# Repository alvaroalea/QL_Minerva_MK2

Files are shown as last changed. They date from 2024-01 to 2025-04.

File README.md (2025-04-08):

# SINCLAIR QL - Minerva MK II - New OS + RTC

In 2024 by Alvaro Alea Fernandez

License under: CERN Open Hardware Licence Version 2 - Strongly Reciprocal

https://ohwr.org/cern_ohl_s_v2.txt

My work is only copy the design to Kicad, all (C) are retaing to the original owners.

U1 shall be pin row, to be mounted in the solder side, in a way that allow to insert on the Sinclair QL's Rom socket.

U5 shall be solder without socket under U2.

U2 shall be solder with a socket to allow space for U5.

Original Information of minerva can be found here: http://tfs.firshman.co.uk/ql/minerva.htm

A generic description here: https://wiki.qlforum.co.uk/doku.php?id=qlwiki:minerva

Manuals and software here: https://dilwyn.qlforum.co.uk/docs/manuals/index.html

Main information, GAL code, pictures, etc... has been obtained from this post: https://qlforum.co.uk/viewtopic.php?t=1993

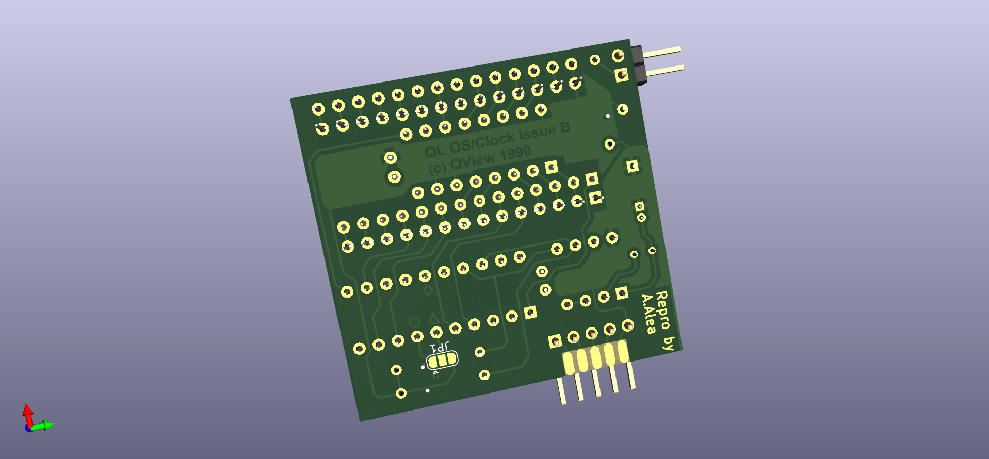
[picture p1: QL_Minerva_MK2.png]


ROM Chip shall be installed as per this picture:

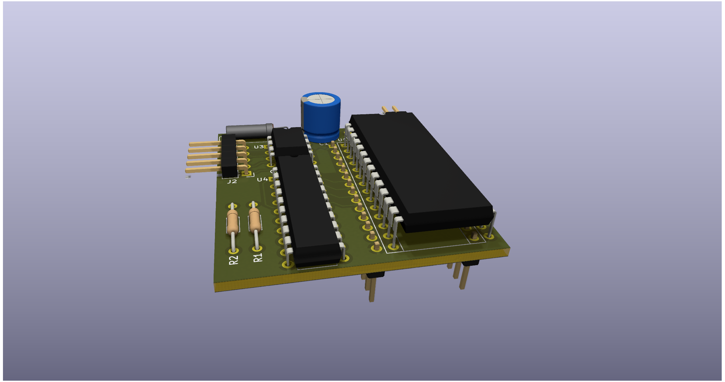
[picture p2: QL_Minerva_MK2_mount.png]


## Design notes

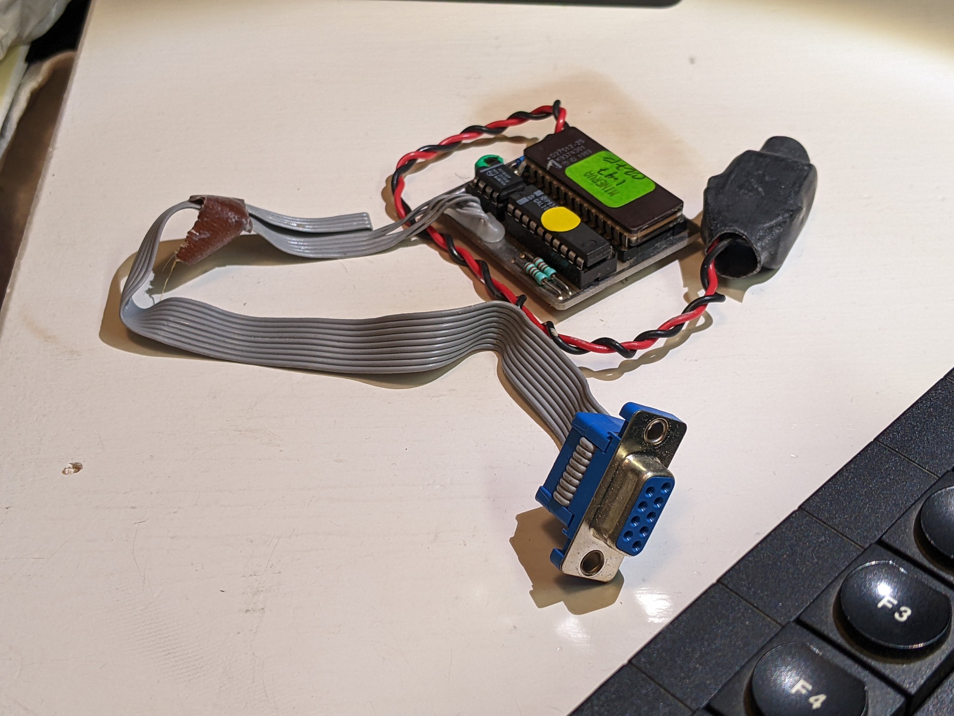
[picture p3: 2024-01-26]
docs_and_pics/417425589_10160796980898964_1513806570932412585_n.jpg

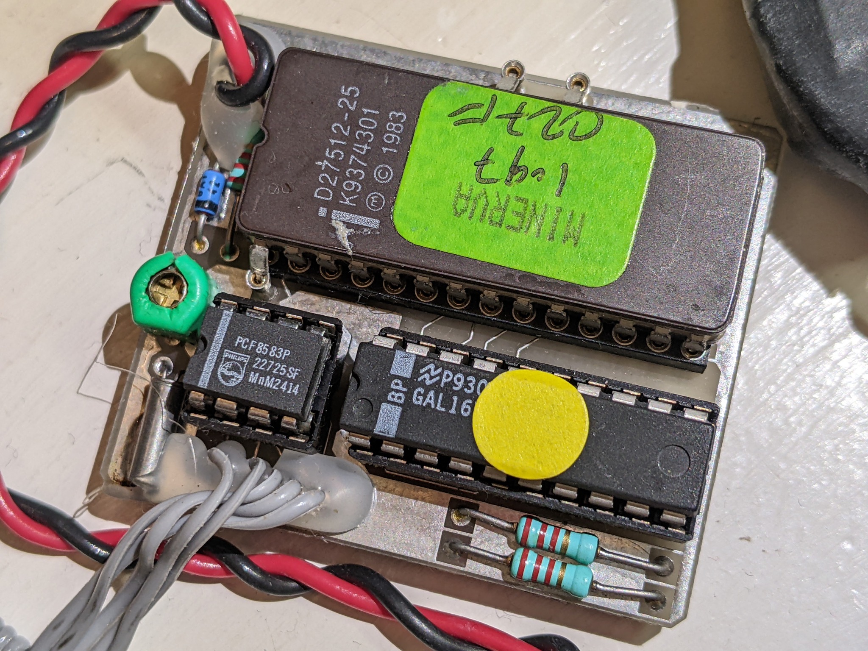
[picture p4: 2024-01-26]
docs_and_pics/417457922_10160796980883964_8911913954346071387_n.jpg

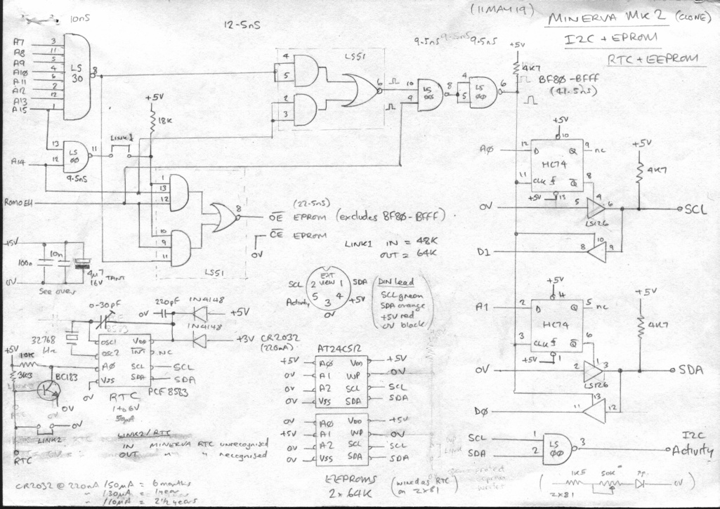
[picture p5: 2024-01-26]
docs_and_pics/MK2clone.JPG

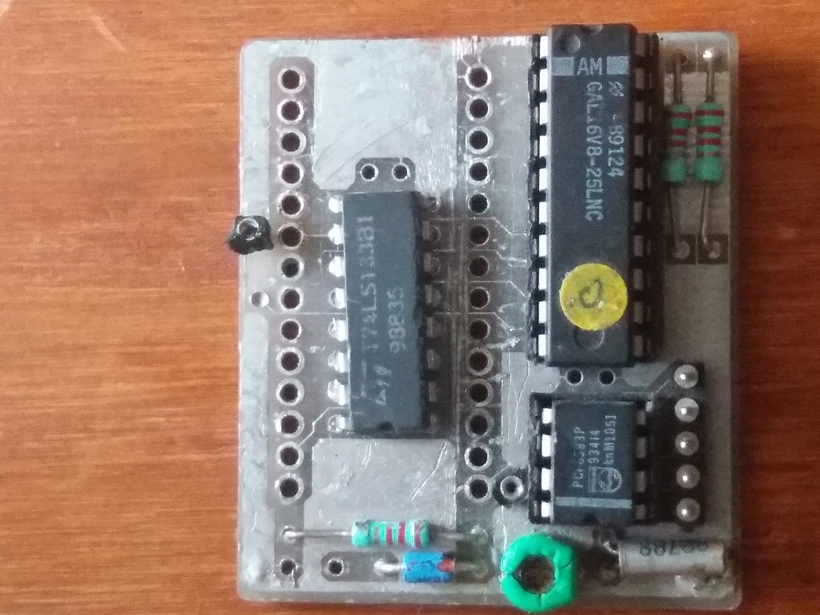
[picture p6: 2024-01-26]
docs_and_pics/MinervaMKII-1.jpg

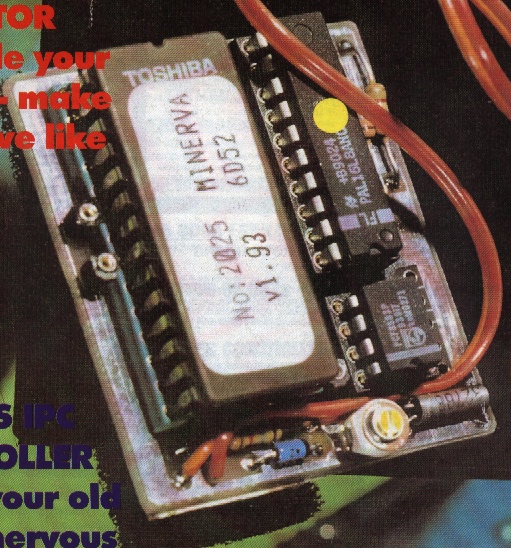
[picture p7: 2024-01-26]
docs_and_pics/Mk2photo.JPG

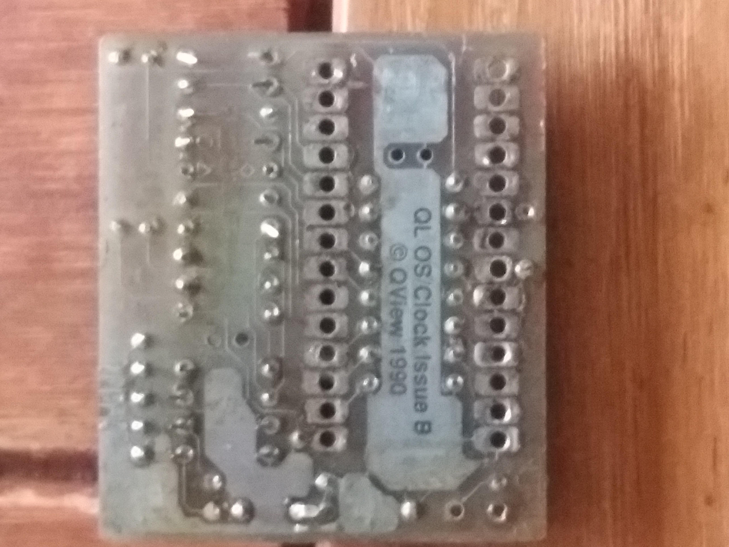
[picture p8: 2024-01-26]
docs_and_pics/MinervaMKII-3.jpg

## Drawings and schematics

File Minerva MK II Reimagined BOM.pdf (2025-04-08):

# Minerva MK II Reimagi… Rev: 0.0

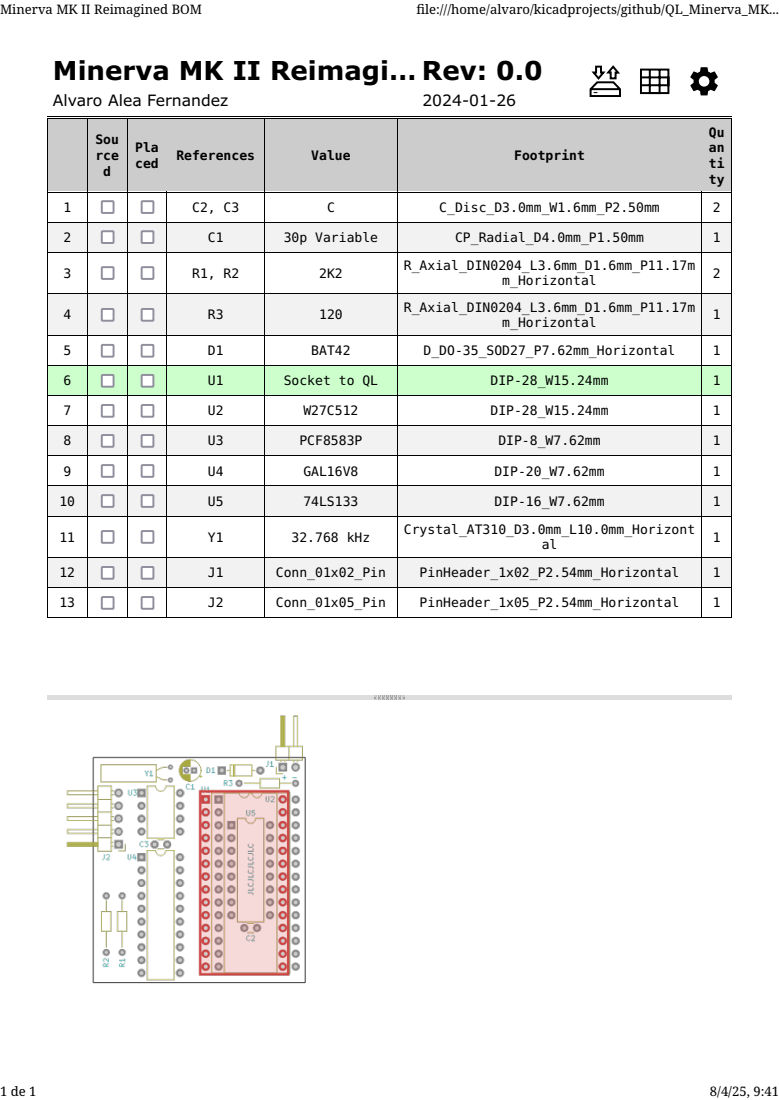
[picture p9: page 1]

Sou rce d | Pla ced | References | Value | Footprint | Qu an ti ty

1 | | | C2, C3 | C | C_Disc_D3.0mm_W1.6mm_P2.50mm | 2

2 | | | C1 | 30p Variable | CP_Radial_D4.0mm_P1.50mm | 1

3 | | | R1, R2 | 2K2 | R_Axial_DIN0204_L3.6mm_D1.6mm_P11.17m m_Horizontal | 2

4 | | | R3 | 120 | R_Axial_DIN0204_L3.6mm_D1.6mm_P11.17m m_Horizontal | 1

5 | | | D1 | BAT42 | D_DO-35_SOD27_P7.62mm_Horizontal | 1

6 | | | U1 | Socket to QL | DIP-28_W15.24mm | 1

7 | | | U2 | W27C512 | DIP-28_W15.24mm | 1

8 | | | U3 | PCF8583P | DIP-8_W7.62mm | 1

9 | | | U4 | GAL16V8 | DIP-20_W7.62mm | 1

10 | | | U5 | 74LS133 | DIP-16_W7.62mm | 1

11 | | | Y1 | 32.768 kHz | Crystal_AT310_D3.0mm_L10.0mm_Horizont al | 1

12 | | | J1 | Conn_01x02_Pin | PinHeader_1x02_P2.54mm_Horizontal | 1

13 | | | J2 | Conn_01x05_Pin | PinHeader_1x05_P2.54mm_Horizontal | 1

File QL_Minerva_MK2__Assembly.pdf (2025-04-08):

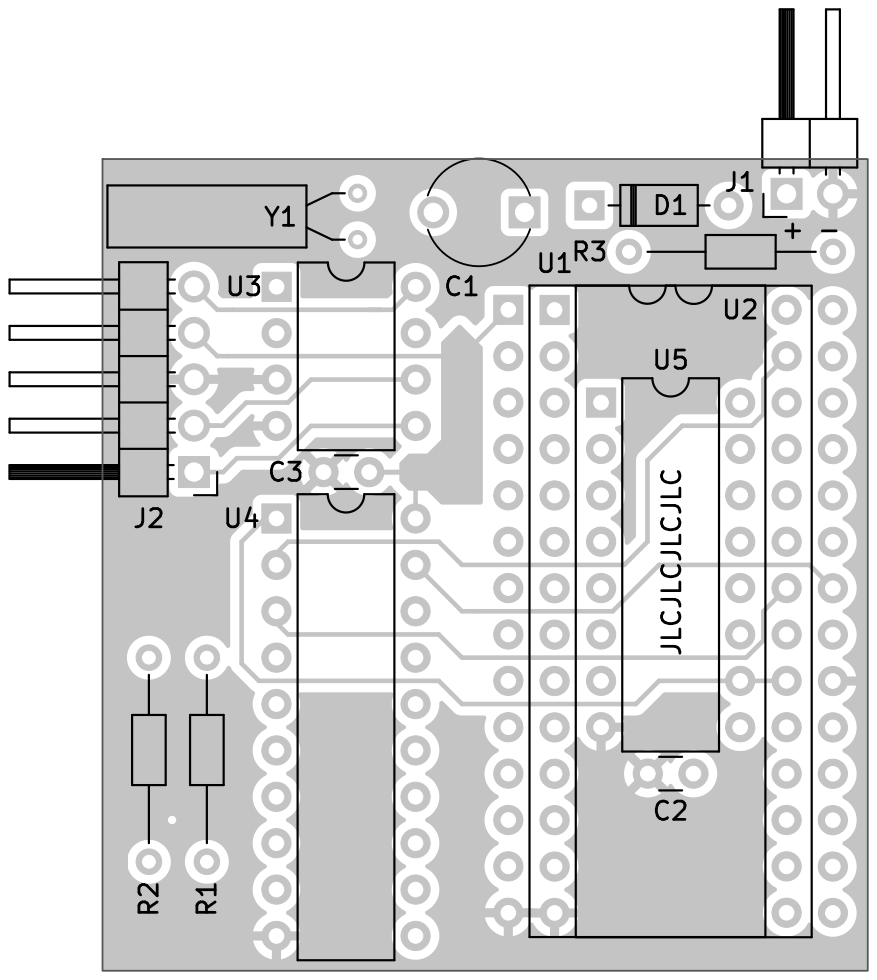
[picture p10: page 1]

Id: /1 Title: Minerva MK II Reimagined

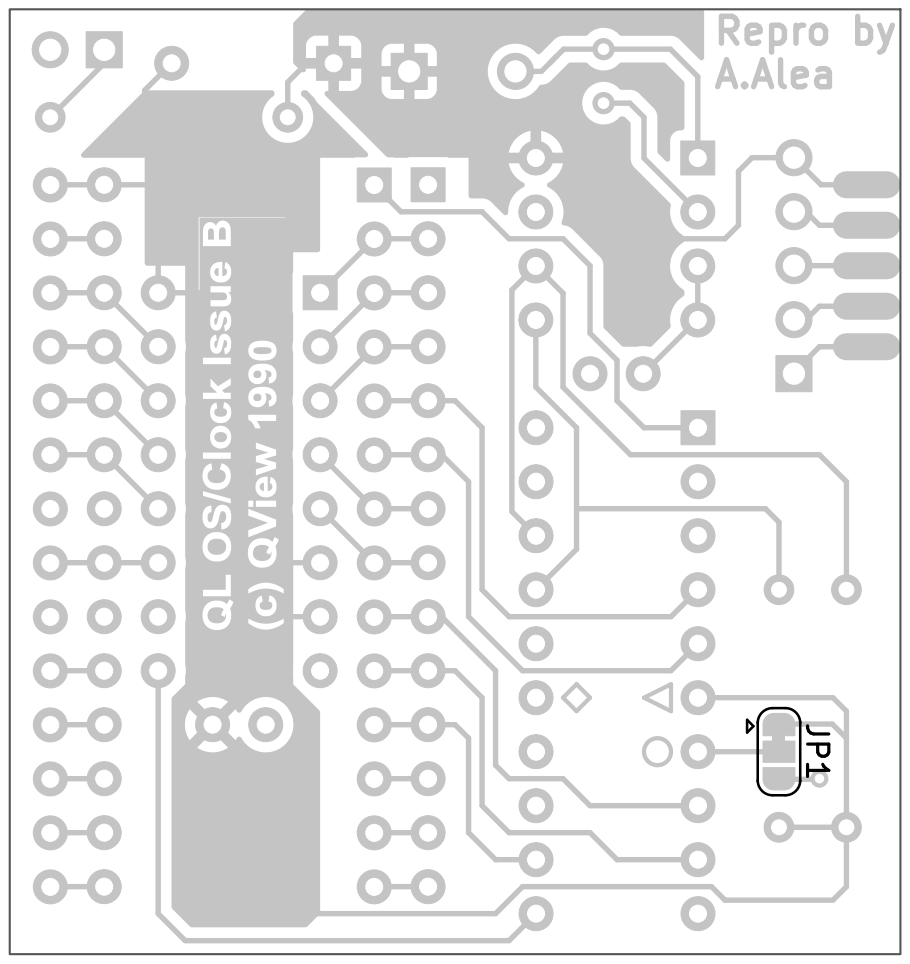
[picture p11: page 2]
Repro by A.AleaJP1; D Date: 2024-01-26 KiCad; E.D.A. 9.0.0 Size: A4; Rev: 0.0; File: QL_Minerva_MK2.kicad_pcb Sheet: Black; And; White; BOT Alvaro Alea; Fernandez Board2Pdf:; Black; BOT -; Page 2/4

Id: /1 Title: Minerva MK II Reimagined

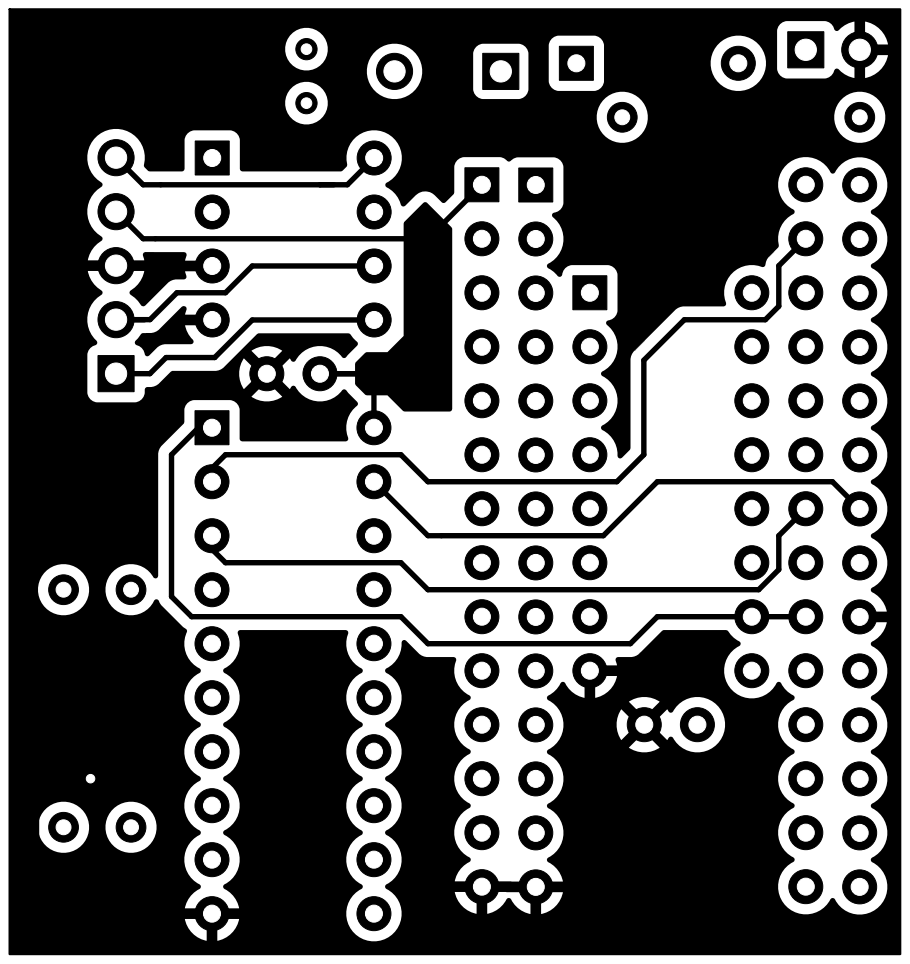
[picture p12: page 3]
D Date: 2024-01-26 KiCad; E.D.A. 9.0.0 Size: A4; Rev: 0.0; File: QL_Minerva_MK2.kicad_pcb Sheet: Black; And; White; TOP-Tracks Alvaro Alea; Fernandez Board2Pdf:; Black; TOP-Tracks; Page 3/4

Id: /1 Title: Minerva MK II Reimagined

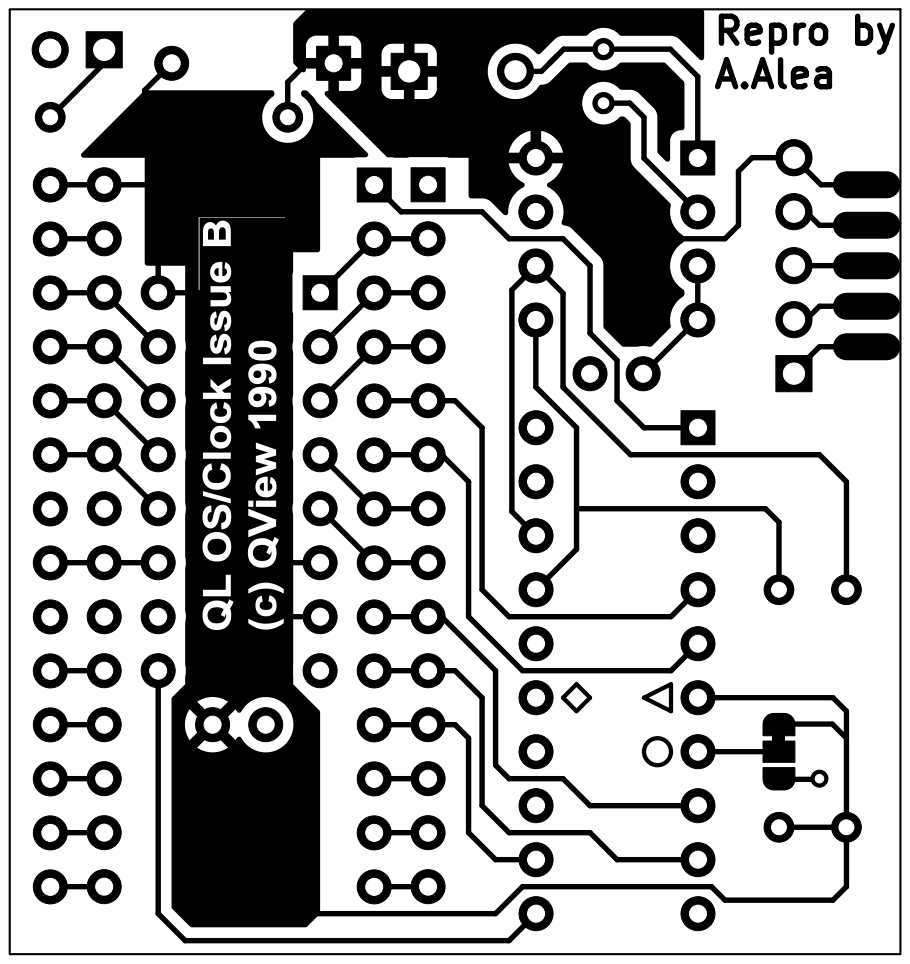
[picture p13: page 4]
Repro by A.Alea 1; D Date: 2024-01-26 KiCad; E.D.A. 9.0.0 Size: A4; Rev: 0.0; File: QL_Minerva_MK2.kicad_pcb Sheet: Black; And; White; BOT-Tracks Alvaro Alea; Fernandez Board2Pdf:; Black; BOT-Tracks; Page 4/4

Id: /1 Title: Minerva MK II Reimagined

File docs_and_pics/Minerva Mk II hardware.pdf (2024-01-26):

## PCB layout and schematic

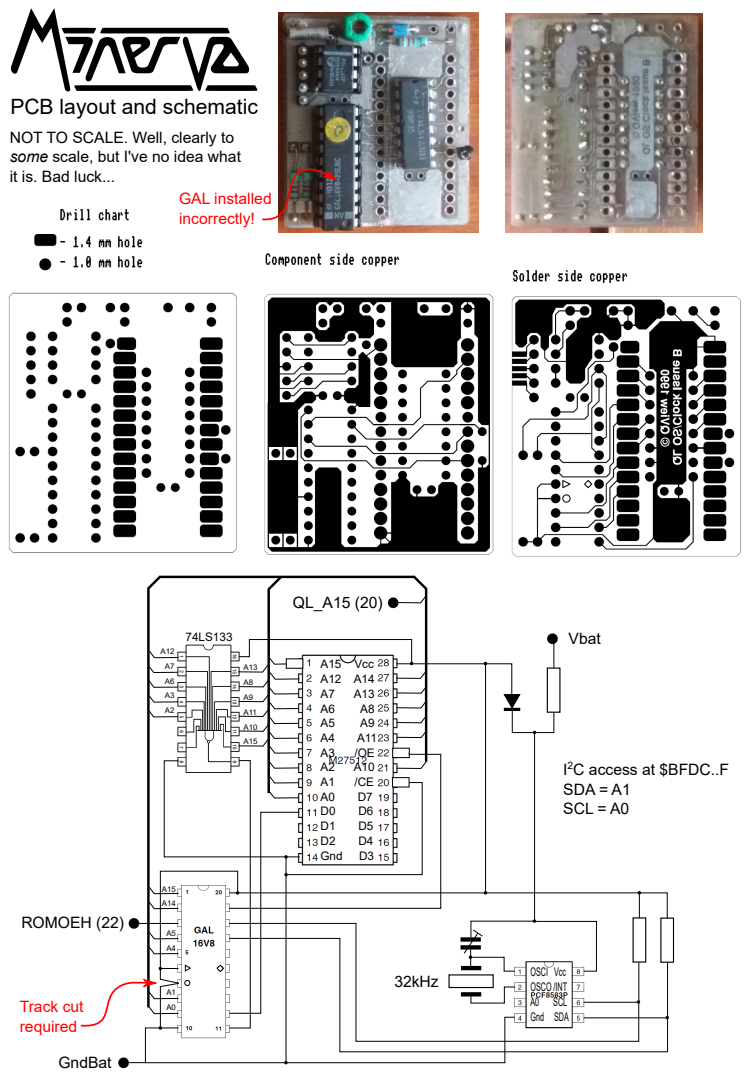
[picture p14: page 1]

NOT TO SCALE. Well, clearly to
some scale, but I've no idea what
it is. Bad luck...

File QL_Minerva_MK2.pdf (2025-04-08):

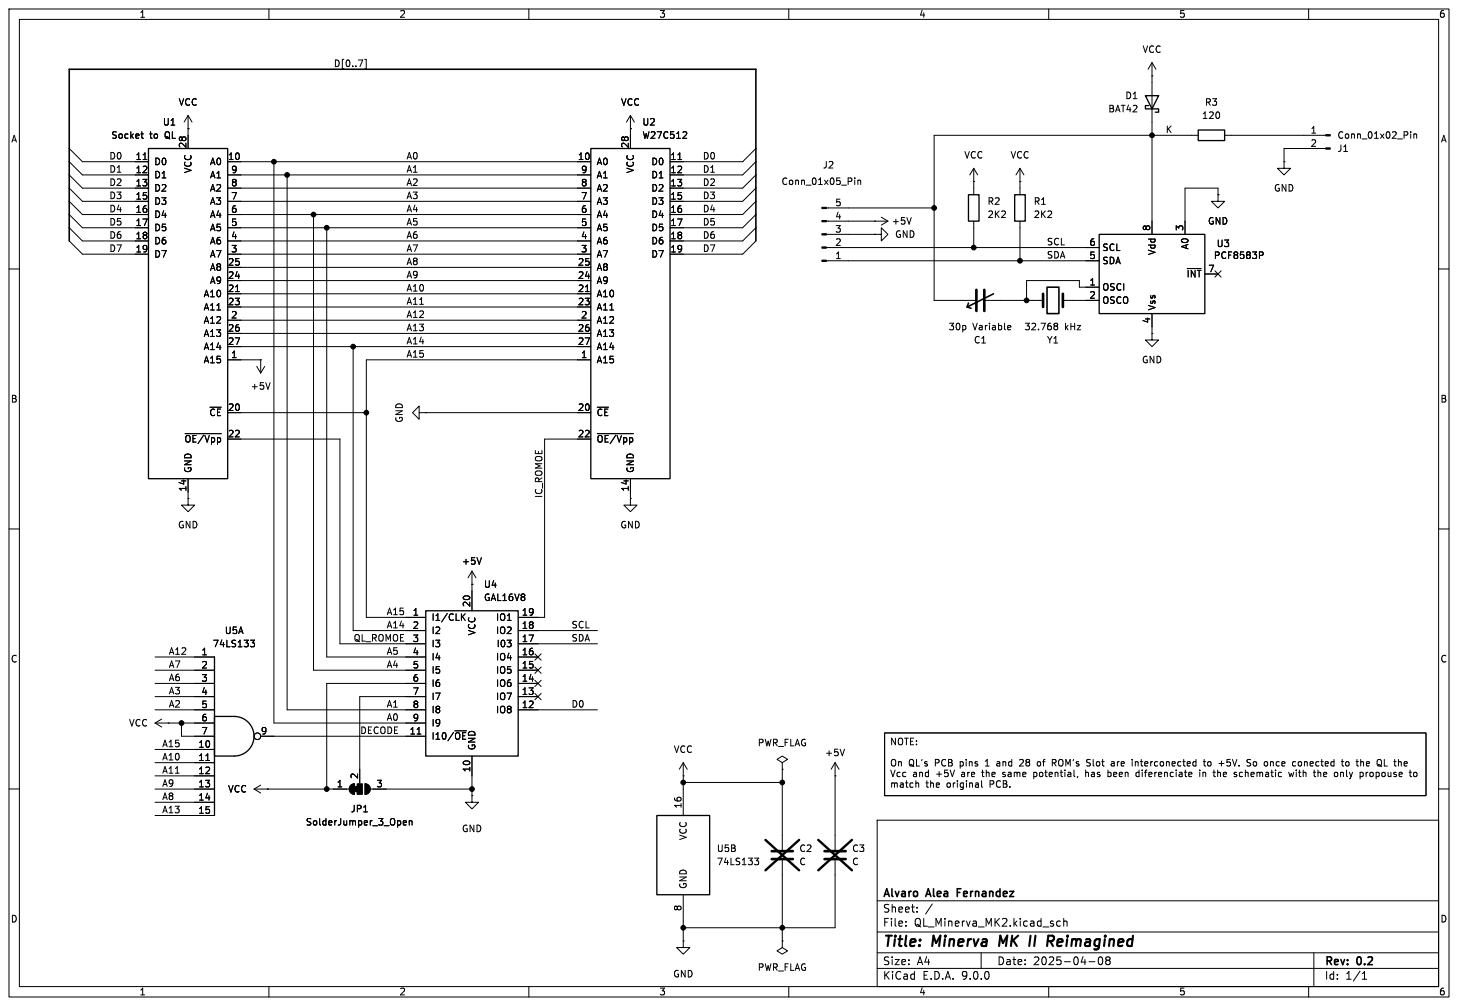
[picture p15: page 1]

Id: 1/1 Title: Minerva MK II Reimagined

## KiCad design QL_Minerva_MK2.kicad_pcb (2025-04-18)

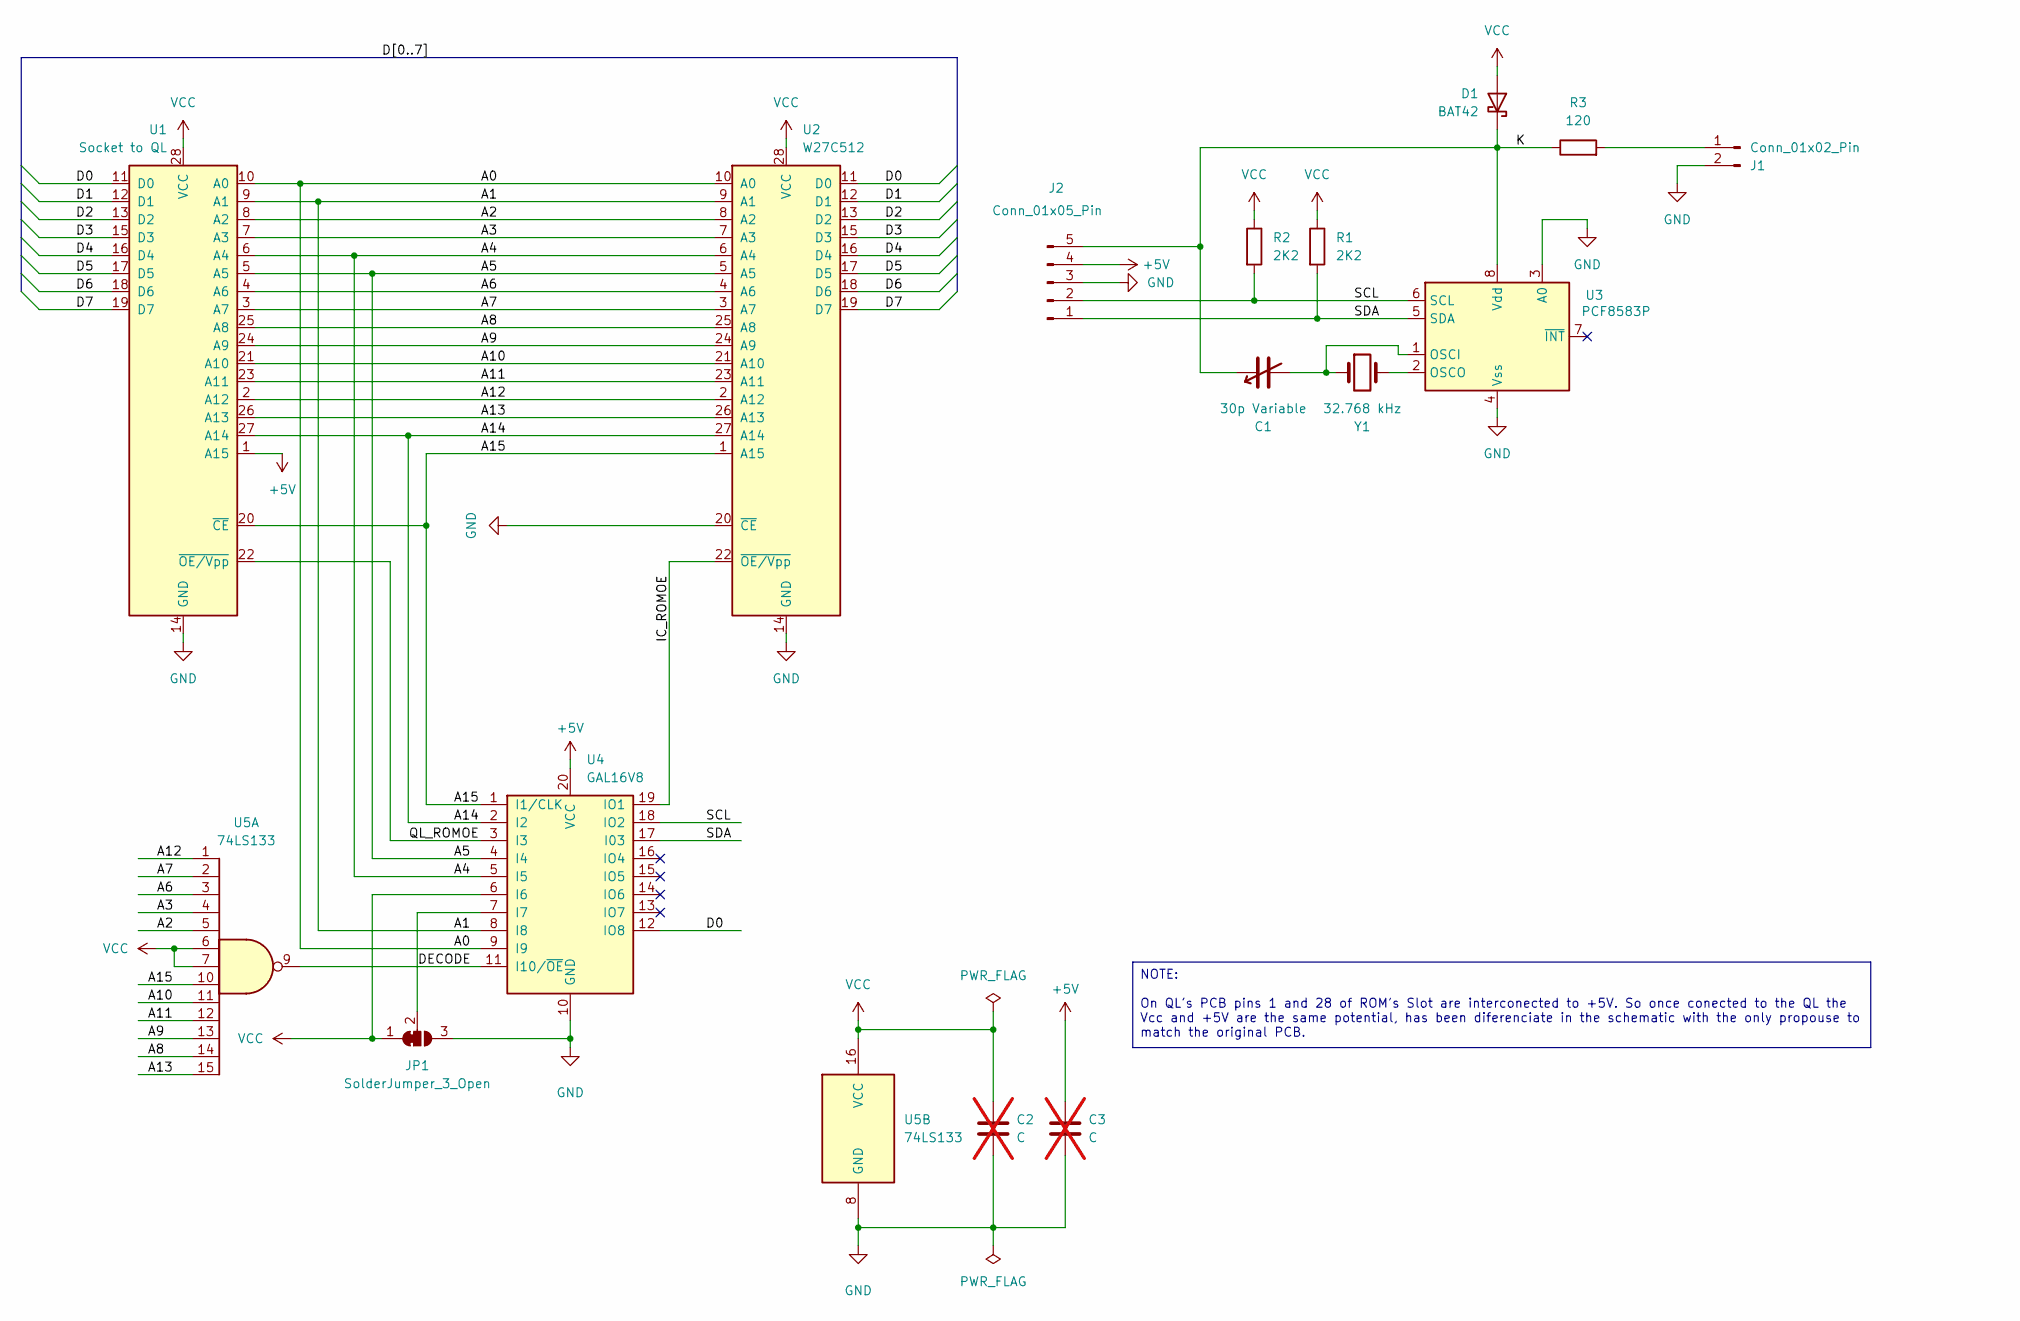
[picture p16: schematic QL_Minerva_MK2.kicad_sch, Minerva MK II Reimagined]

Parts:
C1: 30p Variable; C_Variable_Radial_D6.0mm_P5.00mm
C2, C3: C; C_Disc_D3.0mm_W1.6mm_P2.50mm; not fitted
D1: BAT42; D_DO-35_SOD27_P7.62mm_Horizontal
J1: Conn_01x02_Pin; PinHeader_1x02_P2.54mm_Horizontal
J2: Conn_01x05_Pin; PinHeader_1x05_P2.54mm_Horizontal
JP1: SolderJumper_3_Open; SolderJumper-3_P1.3mm_Bridged12_RoundedPad1.0x1.5mm
R1, R2: 2K2; R_Axial_DIN0204_L3.6mm_D1.6mm_P11.17mm_Horizontal
R3: 120; R_Axial_DIN0204_L3.6mm_D1.6mm_P11.17mm_Horizontal
U1: Socket to QL; DIP-28_W15.24mm
U2: W27C512; DIP-28_W15.24mm
U3: PCF8583P; DIP-8_W7.62mm
U4: GAL16V8; DIP-20_W7.62mm
U5: 74LS133; DIP-16_W7.62mm
Y1: 32.768 kHz; Crystal_AT310_D3.0mm_L10.0mm_Horizontal

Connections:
+5V: C3.1, J2.4, U1.1 (A15), U4.20 (VCC)
/A0: U1.10 (A0), U2.10 (A0), U4.9 (I9)
/A1: U1.9 (A1), U2.9 (A1), U4.8 (I8)
/A2: U1.8 (A2), U2.8 (A2), U5.5
/A3: U1.7 (A3), U2.7 (A3), U5.4
/A4: U1.6 (A4), U2.6 (A4), U4.5 (I5)
/A5: U1.5 (A5), U2.5 (A5), U4.4 (I4)
/A6: U1.4 (A6), U2.4 (A6), U5.3
/A7: U1.3 (A7), U2.3 (A7), U5.2
/A8: U1.25 (A8), U2.25 (A8), U5.14
/A9: U1.24 (A9), U2.24 (A9), U5.13
/A10: U1.21 (A10), U2.21 (A10), U5.11
/A11: U1.23 (A11), U2.23 (A11), U5.12
/A12: U1.2 (A12), U2.2 (A12), U5.1
/A13: U1.26 (A13), U2.26 (A13), U5.15
/A14: U1.27 (A14), U2.27 (A14), U4.2 (I2)
/A15: U1.20 (~CE), U2.1 (A15), U4.1 (I1/CLK), U5.10
/D0: U1.11 (D0), U2.11 (D0), U4.12 (IO8)
/D1: U1.12 (D1), U2.12 (D1)
/D2: U1.13 (D2), U2.13 (D2)
/D3: U1.15 (D3), U2.15 (D3)
/D4: U1.16 (D4), U2.16 (D4)
/D5: U1.17 (D5), U2.17 (D5)
/D6: U1.18 (D6), U2.18 (D6)
/D7: U1.19 (D7), U2.19 (D7)
/IC_ROMOE: U2.22 (~OE/Vpp), U4.19 (IO1)
/K: C1.1, D1.1 (K), J2.5, R3.1, U3.8 (Vdd)
/QL_ROMOE: U1.22 (~OE/Vpp), U4.3 (I3)
/SCL: J2.2, R2.2, U3.6 (SCL), U4.18 (IO2)
/SDA: J2.1, R1.2, U3.5 (SDA), U4.17 (I03)
GND: C2.2, C3.2, J1.2, J2.3, JP1.3 (B), U1.14 (GND), U2.14 (GND), U2.20 (~CE), U3.3 (A0), U3.4 (Vss), U4.10 (GND), U5.8 (GND)
unnamed: J1.1, R3.2
unnamed: C1.2, U3.1 (OSCI), Y1.1
unnamed: U3.2 (OSCO), Y1.2
VCC: C2.1, D1.2 (A), JP1.1 (A), R1.1, R2.1, U1.28 (VCC), U2.28 (VCC), U4.6 (I6), U5.6, U5.7, U5.16 (VCC)

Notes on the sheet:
NOTE: On QL's PCB pins 1 and 28 of ROM's Slot are interconected to +5V. So once conected to the QL the Vcc and +5V are the same potential, has been diferenciate in the schematic with the only propouse to match the original PCB.

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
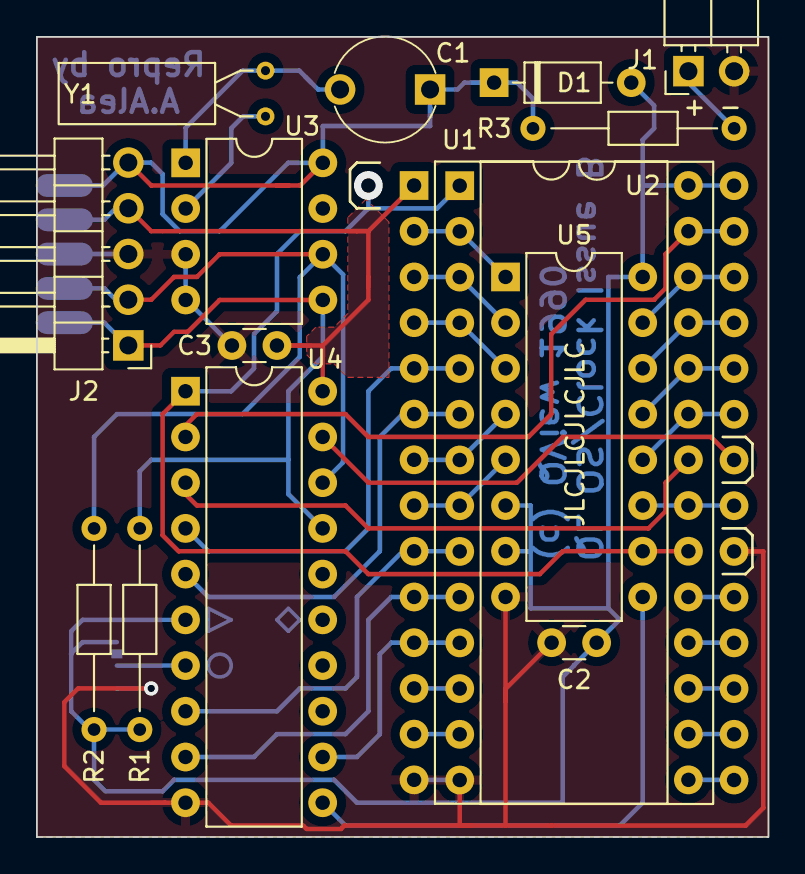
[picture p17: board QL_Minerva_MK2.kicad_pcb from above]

Board: 2 copper layers, 40.6 x 44.5 mm, 16 parts (1 on the bottom side), 37 nets.

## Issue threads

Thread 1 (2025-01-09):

8563/8583

arleybls, 2025-01-09:
You have in the schematic a 8563 instead ofa 8583. Is that correct?

alvaroalea, 2025-02-23:
Correct is PCF8583P. Thanks of inform of the error. I already correct it in the schematic.
Please, I'm not test this board, and I'm not sure about jumpers on pin 6,7 of GAL, if you test, please give me feedback.

arleybls, 2025-03-12:
Hey. I will do a small batch to test. That capacitor footprint is (probably) not correct, I think it shall be a trimmer 0-30 and legs are probably wider as well.

alvaroalea, 2025-03-16:
Yes, capacitor is like reference JML06-1 that can be found on internet, as per color of pictures of original board, yes is 30pF, and has the legs at 5mm, not 2,5 as in the PCB, I will update the PCB, sorry, hopefully you can solder it anyway.

arleybls, 2025-03-24:
Got black screen, tried with 30 and a 15pf fixed mlcc capacitors (waiting for trimmers)

alvaroalea, 2025-04-08:
Hi, I found the error, pin 7 of the GAL is tied to GND and need to be to VCC (along with pin 6), you need to leave the pin outside of the IC socket and wire to the botton of the resistor R1/R2.

arleybls, 2025-04-16:
Can confirm it is now working.

Closed 2025-03-25.

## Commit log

2024-01-27 update pin 6 of GAL
    [QL_Minerva_MK2-B_Cu.gbr, QL_Minerva_MK2-B_Mask.gbr, QL_Minerva_MK2-B_Paste.gbr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]
2024-04-28 add values of components
    [QL_Minerva_MK2-B_Cu.gbr, QL_Minerva_MK2-B_Mask.gbr, QL_Minerva_MK2-B_Paste.gbr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]
2025-02-23 Fix references
    [QL_Minerva_MK2-B_Cu.gbr, QL_Minerva_MK2-B_Mask.gbr, QL_Minerva_MK2-B_Paste.gbp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]
2025-03-25 update C footprint
    [QL_Minerva_MK2-B_Cu.gbr, QL_Minerva_MK2-B_Mask.gbr, QL_Minerva_MK2-B_Paste.gbp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]
2025-04-08 fixed error in leg 7 of gal
    [QL_Minerva_MK2.kicad_pcb, QL_Minerva_MK2.kicad_sch]
2025-04-18 Reduced size to avoid colision with cristal of QL Mainboard
    [QL_Minerva_MK2.kicad_pcb]
